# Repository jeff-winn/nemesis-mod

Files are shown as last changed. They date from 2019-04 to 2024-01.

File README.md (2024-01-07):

# Nemesis Mod
It started off as me just wanting to play with an Arduino while repurposing some old .NET Gadgeteer hardware I had laying around the house. It turned into quite a bit more than that over the months that I worked on it. Hopefully the source code will help someone interested in replicating the success I had with my project with their own. Happy coding!

| Branch | Status |
| --- | ---|
| master |   |

## Setting up your environment
Because this project requires the use of symbolic links, you will need to use the command line to clone the repository. Visual Studio Code can do it, but it does not permit symbolic links by default.

```shell
git clone -c core.symlinks=true 
```

## Hardware Requirements
These are the boards and hardware being used by the project:
- [Adafruit Feather M4 Express](https://www.adafruit.com/product/3857) - Mainboard sketch
- [Adafruit Micro SD SPI or SDIO Card Breakout Board](https://www.adafruit.com/product/4682)
- [Tactile Button Switch (6mm square, 5mm tall)](https://www.adafruit.com/product/367)
- [Pololu Dual G2 High-Power Motor Driver 18v18 Shield for Arduino](https://www.pololu.com/product/2515)
- [Pololu G2 High-Power Motor Driver 18v17](https://www.pololu.com/product/2991)
- [Pololu 5V, 500mA Step-Down Voltage Regulator](https://www.pololu.com/product/2843)

### Optional Hardware
- [Adafruit Feather nRF52840 Express](https://www.adafruit.com/product/4062) - Bluetooth sketch
- [MaxAmps LiPo 3250 3S 11.1v Battery Pack](https://www.maxamps.com/lipo-3250-3s-11-1v-battery-pack)

## Bluetooth Support
If you wish to use the Bluetooth connectivity included with this device, please see the Wiki page.

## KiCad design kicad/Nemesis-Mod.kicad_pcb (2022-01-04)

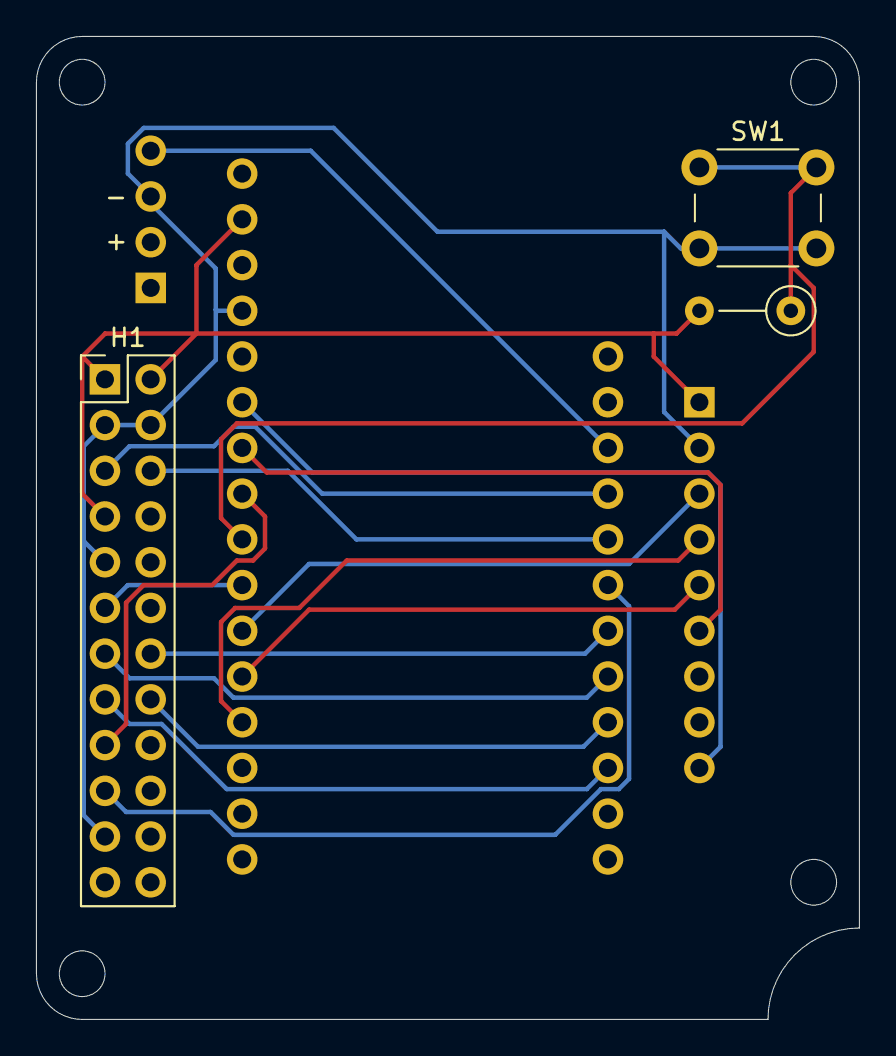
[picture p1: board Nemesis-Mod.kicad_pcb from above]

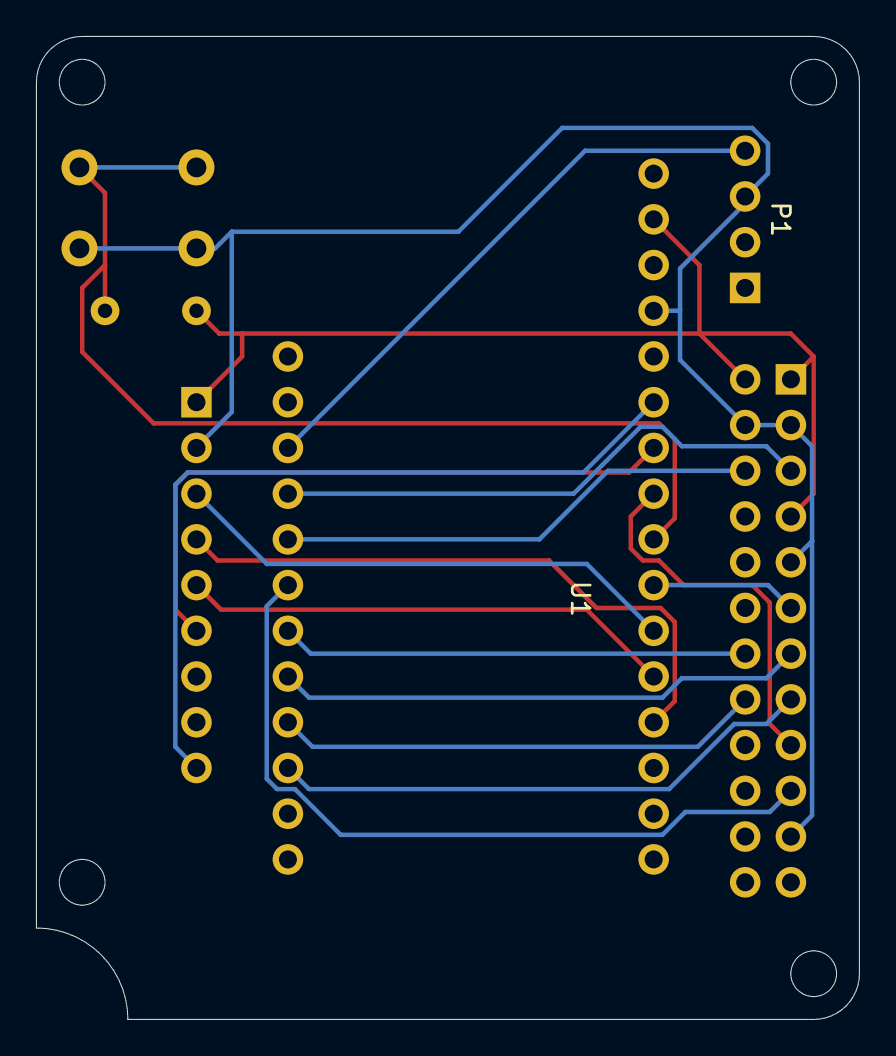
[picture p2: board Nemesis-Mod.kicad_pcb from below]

Board: 2 copper layers, 45.7 x 54.6 mm, 6 parts (2 on the bottom side), 18 nets.

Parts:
H1: PinHeader_2x12_P2.54mm_Vertical
MCU1: Adafruit_Feather_M4_Express
P1: Pololu_5V_Step_Down_Regulator; 5V_Step_Down_Regulator_500mA
R1: 10K; R_Axial_DIN0207_L6.3mm_D2.5mm_P5.08mm_Vertical
SW1: SW1; SW_PUSH_6mm
U1: Adafruit_MicroSD_SPI_Breakout; Adafruit_MicroSD_Breakout

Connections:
+3V3: H1.1, H1.2, H1.7, MCU1.2 (3V), R1.2, U1.1 (3V)
+5V: MCU1.19 (USB), P1.4 (VOUT)
/Mainboard/FIRE_DOWN: H1.6, MCU1.21 (12)
/Mainboard/M1PWM: H1.15, MCU1.26 (5)
/Mainboard/M1SLP: H1.13, MCU1.24 (9)
/Mainboard/M2PWM: H1.16, MCU1.25 (6)
/Mainboard/M2SLP: H1.14, MCU1.23 (10)
/Mainboard/M3PWM: H1.19, MCU1.22 (11)
/Mainboard/M3SLP: H1.17, MCU1.8 (A3)
/Mainboard/RESET_DOWN: MCU1.9 (A4), R1.1, SW1.1
/Mainboard/REV_DOWN: H1.5, MCU1.20 (13)
/Mainboard/SD_DETECT: MCU1.6 (A1), U1.9 (DET)
/Mainboard/SD_SELECT: MCU1.7 (A2), U1.6 (CS)
/Mainboard/SOFT_LOCK1: H1.11, MCU1.10 (A5)
/Mainboard/SPI_CLK: MCU1.11 (SCK), U1.3 (CLK)
/Mainboard/SPI_M_IN: MCU1.13 (MI), U1.4 (SO)
/Mainboard/SPI_M_OUT: MCU1.12 (MO), U1.5 (SI)
GND: H1.3, H1.4, H1.9, H1.21, MCU1.4 (Gnd), P1.3 (GND), SW1.2, U1.2 (GND)

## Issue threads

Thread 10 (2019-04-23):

Add a battery kill switch

jeff-winn, 2019-04-23:
The LiPo pack will need a voltage monitor attached to a kill switch on the firing loop.

This ensures the battery stays within a safe operating voltage to prevent it from being damaged.

jeff-winn, 2019-05-13:
This will need a JST-XH connector and a 5V to 3.3V logic level converter as the LiPo pack has a 4.2V output at full charge from the battery balance connector.

Possible product:
https://www.adafruit.com/product/757

jeff-winn, 2019-11-12:
This would be nice if the BLEBas service can be added within the BluetoothController setup in #42 to display battery levels remotely.

jeff-winn, 2019-11-18:
https://www.adafruit./product/1085

The above ADS1115 product was selected for identifying the battery levels.

jeff-winn, 2019-11-18:
A new battery monitor service needs to be added so the notifications from the battery and the ADS1115 can be transmitted to the BluetoothController and exposed by the BLEBas service.

jeff-winn, 2021-12-02:
Duplicate of #80

Closed 2021-12-02.

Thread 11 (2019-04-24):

Rework for 18v17 motor driver

jeff-winn, 2019-04-24:
The Pololu G2 18v17 motor driver needs to be installed to drive the belt motor.

Closed 2019-04-26.

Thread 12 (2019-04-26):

Optimize the motor speeds

jeff-winn, 2019-04-26:
The flywheel and feed controllers both contain values that determine the motor speeds at the various MotorSpeed enum values.

These values need to be optimized for best case scenarios to ensure proper operation. Specifically the belt drive when on max setting is so fast the rounds just bounce out of the belt and the agitator throws them back up into the hopper.

Closed 2019-05-22.

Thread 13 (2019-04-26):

Add hopper lock switch support

jeff-winn, 2019-04-26:
The hopper lock switch needs to be added to the design. The initial idea would just use an interrupt based software lock to prevent the blaster firing without the hopper installed.

Closed 2019-04-27.

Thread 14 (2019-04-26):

Add support for the 5V stepdown voltage regulator

jeff-winn, 2019-04-26:
The 5V voltage regulator needs to be installed between the 18v18 motor shield and the Feather.

https://www.pololu.com/product/2843

Also consider adding a USB Power Multiplexer to allow the battery pack to remain connected while also allowing a panel mounted USB port allowing external reprogramming of the device. This will still require the 5V voltage regulator if this option were implemented.

https://www.pololu.com/product/2596

Closed 2019-04-27.

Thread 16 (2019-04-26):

Need means of authenticating the operator

jeff-winn, 2019-04-26:
Currently the authentication lock is disabled but in order to enable speeds higher than the default the operator must have a means of authenticating themselves.

Possibilities:
- Bluetooth and a connected app with fingerprint recognition
- Built in biometric fingerprint reader

jeff-winn, 2019-05-26:
This issue will be solved using the Bluetooth and connected application route using an authenticate command.

See #28 for more information.

jeff-winn, 2019-06-24:
This item will need issue #25 completed to ensure the data passed along during authentication is validated against data stored on the device.

Closed 2019-06-30.

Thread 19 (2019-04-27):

Add power multiplexer

jeff-winn, 2019-04-27:
Need to add a USB power multiplexer to handle power switching and external programming support for the blaster while it's pieced together.

Potential product:
https://www.pololu.com/product/2596
https://www.adafruit.com/product/3258

The panel mount could be used to plug into the multiplexer, and use the second pins to receive power from 5V power regulator. This option would also require having a USB Micro B breakout cable connect from the output pins into the Feather USB Micro B.

Closed 2019-06-26.

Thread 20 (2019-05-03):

Stops firing occasionally

jeff-winn, 2019-05-03:
Not entirely sure what the source of the problem is however here are the symptoms:

- Both flywheel motors stop turning (most commonly seen after extended use)
- Single flywheel motor stops turning (usually results in the second flywheel motor seeing a significant speed increase)
- Belt drive motor stops turning

jeff-winn, 2019-05-16:
Doesn't seem to be related to the either Pololu driver, after bypassing the triggers and forcing the rev and firing triggers to be high the drivers operated as expected with continuous current.

jeff-winn, 2019-05-16:
Regarding the previous comment, the motors were not connected to the drivers at this point.

jeff-winn, 2019-05-16:
Rapidly enabling and disabling the rev trigger the M2 output pins on the 18v18 shield worked as expected.

jeff-winn, 2019-05-16:
Able to replicate the issue using a jumper from the power line directly to pin 13. The motor driver was operating as expected with 11VDC on the output going toward the motors. At the motor was the 11 VDC as well, but the motors were not spinning.

jeff-winn, 2019-05-17:
Second attempt to replicate the issue again using the above method proved successful, the boards underneath the motors had the 11 VDC, but were not passing the current into the motors.

jeff-winn, 2019-05-18:
The issue could be related to the way the braking was being done when the triggers were pressed and released rapidly. Modifying the code to give the motors a slowed braking versus massive braking directly to zero seems to have a positive effect on the capacitors near the motors.

Also, rewired the FLT pins to the SLP pins to allow the microcontroller disabling the motor driver and allowing the motors to coast to a stop.

jeff-winn, 2019-05-20:
The code changes to use a slowed braking had no impact on the capability for the motors to run longer than 30 seconds. Removed the stock board underneath the motors with the leads soldered directly to the wires.

Will likely need another change to solder capacitors from the terminals to the motor case to reduce signal noise. Possibly using the capacitors that were on the board.

jeff-winn, 2019-05-20:
After speaking to some folks on Slack, there is a component in the center of the board below that may be a polyfuse (aka resettable fuse) which is disabling the motors due to the increased current.

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

jeff-winn, 2019-05-20:
After further investigation, the component in the center is an HR16-110 PPTC resettable fuse which is likely the culprit why it would stop firing after 30 seconds, and then couldn't fire again for a while after. The electrical characteristics for the part indicates it'd take an hour our two for it to recover.

Considering removal of the component and using a jumper between the two pins.

jeff-winn, 2019-05-20:
The board used for the belt feed had a similar component on it as well near the positive terminal as HR16-065. The approach used to correct the flywheel assembly would need to be replicated on this component board as well.

Closed 2019-05-20.

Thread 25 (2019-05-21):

Unable to retain settings beyond reset

jeff-winn, 2019-05-21:
The hardware does not support EEPROM or FRAM for storage of configuration settings that persist beyond restart of the device.

jeff-winn, 2019-05-23:
Closing as issue #28 will provide better support for configuration and wouldn’t leave the blaster in a potentially harmful configuration if children find it.

jeff-winn, 2019-06-23:
Decided to reopen this so the settings don’t need to be reapplied constantly.

Also the blaster will need some data stored locally to be used to validate what’s being transmitted for authentication.

Closed 2019-06-27.

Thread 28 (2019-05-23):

Need Bluetooth support for configuration

jeff-winn, 2019-05-23:
The Bluefruit LE MCU should be better utilized by handling communication for:

- Diagnostic data
- Trim settings for zero
- Configuration of the belt speed and flywheel speed

jeff-winn, 2019-05-23:
This might be a good way to move settings from the blaster on EEPROM or FRAM into profiles on the connected device that just set all the configurations.

jeff-winn, 2019-06-10:
Merged to master

Closed 2019-06-10.

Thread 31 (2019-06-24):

Need command to set authentication data

jeff-winn, 2019-06-24:
There needs to be a command which will set the authentication data on the device if none is present, or require the operator to authenticate prior to allowing the authentication data to be modified.

jeff-winn, 2019-06-25:
Requires the completion of issue #25 prior to starting this issue.

jeff-winn, 2019-06-29:
Needs the iOS companion application to determine how long the authentication data will be.

jeff-winn, 2019-06-29:
This will be set when the first authentication has been performed, and the reset button on the device being held for 30 seconds or more will allow wiping all the information on the FRAM if needed.

Closed 2019-06-30.

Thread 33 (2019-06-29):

Need to transmit diagnostic data

jeff-winn, 2019-06-29:
The blaster needs to be able to transmit diagnostic data to the iOS companion application for monitoring battery health, current output, etc.

The following data points are required from Motor_Driver_1:
- M1CS
- M2CS

The following data points are required from Motor_Driver_2:
- CS

More information may be added after issue #10 has been closed and something is monitoring the battery health via the balance connector.

jeff-winn, 2019-11-12:
This should now be enabled by #42 and exposing GATT characteristics with no write permission and read only with notification on the client

jeff-winn, 2019-11-18:
The GATT notification characteristics worked as expected. The value from the flywheel M1 and M2 sensors along with the belt M1 sensor has been exposed as characteristics with a read notification with no write privileges.

As the blaster is active it will transmit notifications much more frequently to the connected device.

jeff-winn, 2019-11-18:
Need to connect the blaster up to the battery pack and see what data comes across to the connected device.

Closed 2019-11-28.

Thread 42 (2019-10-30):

Adopt new Feather nRF52 Bluefruit mainboard

jeff-winn, 2019-10-30:
The mainboard needs to be modified to support the nRF52 Bluefruit LE mainboard with ARM M4F chipset.

See:
https://www.adafruit.com/product/3406

jeff-winn, 2019-11-12:
The GATT characteristics and services made it much easier to write the connection mechanism between the companion app and the blaster.

jeff-winn, 2019-11-12:
There should be a waitForEvent method available to the main board which can disable the cpu until GPIO interrupt occurs

jeff-winn, 2019-11-12:
Resolved in #44

Closed 2019-11-12.

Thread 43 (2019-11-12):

Reset button should also clear Bluetooth bonds

jeff-winn, 2019-11-12:
To ensure only a single Bluetooth connection can be established to the blaster, the advertising packets should only be started if the device is not already paired.

Along with this, pressing the reset button should also clear the Bluetooth controller bonds as well as the app data.

Perhaps this also means the reset should be done outside the app control?

jeff-winn, 2019-11-12:
This will be enabled by #42

jeff-winn, 2019-11-13:
The Bluefruit API doesn’t seem to have any methods exposed to indicate whether the device has been paired.

The connected callback must be setup to check whether the handle has been paired and set a setting on the FRAM chip which can be used for the advertisement decision.

Closed 2019-11-27.

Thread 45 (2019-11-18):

Must use pin code while pairing

jeff-winn, 2019-11-18:
The pairing process needs a display to show the pairing value for confirmation by the user on their device.

Without this, the pairing process does not use a secure channel and the blaster never identifies as having been paired (even if pairing has occurred).

To secure the blaster, it must be able to identify whether the connected device has successfully negotiated the pairing process.

jeff-winn, 2019-11-18:
This issue will require the procurement of a display (preferably I2C supported).

jeff-winn, 2019-11-18:
There could be a limitation on the Bluefruit API blocking the implementation of this enhancement.

jeff-winn, 2021-12-08:
Upgraded the firmware on the bluetooth board to version 1.2.0, there appears to be a new security section under Bluefruit that may be usable.

jeff-winn, 2021-12-08:
The board added support for static pin numbers, so that was used rather than setting up a display.

Closed 2021-12-08.

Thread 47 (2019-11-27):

Flywheel speed should change when active

jeff-winn, 2019-11-27:
The flywheel speed currently requires a reset of the trigger to take effect. The expectation is it should be immediate.

Closed 2019-11-28.

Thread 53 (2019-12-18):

Opening the hopper to refill resets the blaster configuration

jeff-winn, 2019-12-18:
Since the hopper lock cuts power to the MCU, whenever the hopper is open the restarting of the MCU causes the settings the shooter is currently using (feed and flywheel speeds) to be reset to their startup configuration.

When used in a battle, this will definitely be an issue with rapidly refilling the rounds in the hopper and resuming play.

jeff-winn, 2019-12-18:
Need to consider removal of the hopper lock, or changing the lock to use an input pin to determine whether the hopper is currently open.

jeff-winn, 2019-12-19:
Rather use a soft lock that can be controlled using a Bluetooth characteristic whether it’s engaged.

This will allow keeping the lock intact when in “kid mode”

Closed 2019-12-21.

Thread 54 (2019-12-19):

Use JST PH connector for power connection

jeff-winn, 2019-12-19:
The current hardware configuration uses the USB pin and GND pins to power the device using the Pololu 5V 500mA step-down voltage regulator.

This regulator should be switched out for a 3.3v 500mA step-down voltage regulator and use a JST PH  2-pin connector to connect to the MCU.

**Example products:**
- [Voltage Regulator](https://www.pololu.com/product/2842)
- [JST PH 2-pin Connector](https://www.adafruit.com/product/261)

jeff-winn, 2019-12-19:
Just wanted to note,

The 3.3V pin on the Pololu high power dual motor controller would be pass through from the Arduino if used as a shield as expected. This pin does not originate from the motor controller and could not be used to power the MCU.

jeff-winn, 2019-12-23:
The primary concern with this connection is the Adafruit board assumes you want to do LiPo charging when a pack and USB are connected.

They’re presuming their small single cell LiPo is directly connected to the board.

jeff-winn, 2019-12-23:
Closing due to concerns about power management. The multiplexer route with USB or the LiPo pack would be better.

Closed 2019-12-23.

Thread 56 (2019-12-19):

Ludicrous speed tearing rounds apart

jeff-winn, 2019-12-19:
With only one set of flywheels getting the rounds up to speed is causing the “yellow dust” effect whereby the rounds are being shredded by the flywheels while firing.

Perhaps using a 2 stage setup to get the rounds up to speed would reduce this effect.

jeff-winn, 2019-12-23:
This might end up being the catalyst to move toward a brushless setup and custom flywheels.

jeff-winn, 2019-12-23:
This problem is not uncommon with rival rounds when using a 3S LiPo battery pack

jeff-winn, 2019-12-23:
Switching to ESCs and brushless motors would require expansion of the PWM signal as the pins on the MCU are limited.

jeff-winn, 2021-12-02:
Removing from R3 as this seems common with a 3S upgrade.

Closed 2021-12-06.

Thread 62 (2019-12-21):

Changing settings occasionally causes the blaster to stop firing (or logging)

jeff-winn, 2019-12-21:
Not sure which this is but if the settings are changed rapidly, the blaster can either stop logging that the blaster is revving and firing, or the blaster is actually rendered inoperable.

jeff-winn, 2019-12-25:
Confirmed this does cause the blaster to cease firing altogether. The rev trigger stops working along with the firing trigger.

jeff-winn, 2019-12-25:
It doesn't stop responding to bluetooth based input, so it could be a bug somewhere in the driver from Adafruit

jeff-winn, 2019-12-25:
This bug could also be due to how the companion app is communicating with the blaster over the GATT services when updating the settings too rapidly.

jeff-winn, 2019-12-25:
When the blaster is frozen it also will not allow attaching to bluetooth GATT notification services. The companion application will freeze when attaching to the device.

jeff-winn, 2019-12-25:
Changing the settings while the blaster was actively in use also caused problems with the device freezing in whichever state it was in (if firing it keeps firing until reset).

jeff-winn, 2019-12-28:
Changing anything via bluetooth while the blaster is revving flywheels will cause the blaster to stop responding along with never leave the loop.

jeff-winn, 2019-12-30:
Changing the setWriteCallback to false when initializing the GATT services does not have any impact on the logic freezing. Perhaps this is a client side issue more than a peripheral side issue?

jeff-winn, 2019-12-30:
The issue is definitely occurring due to the setWriteCallback being used, removing the callbacks negated the issue. However, if the callback is not used, changing the values that are stored on FRAM will be much more difficult as the values would need to be pulled from the GATT characteristics rather than FRAM.

jeff-winn, 2020-09-04:
Had the issue occur again today, I was testing #65 to make sure everything looked good before merging.

jeff-winn, 2021-05-19:
This could be resolved by #71

jeff-winn, 2021-12-04:
Just needs to be triaged whether the bug has been fixed now that the logic has been separated.

jeff-winn, 2021-12-06:
Issue has been resolved by #70 and #71

Closed 2021-12-06.

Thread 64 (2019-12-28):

Add GATT characteristic for battery levels

jeff-winn, 2019-12-28:
The BLEBas service can be used to display battery levels on a device.

Determining the battery voltage at 3.4V per cell at 0% and 4.2V at 100% would be a good indication.

jeff-winn, 2019-12-28:
https://www.adafruit.com/product/4226

Potential product which could be used to measure reference voltage from the battery. Expected use would be in between the flywheel motor shield and the step down converter from Pololu.

jeff-winn, 2021-12-02:
Duplicate of #80

Closed 2021-12-02.

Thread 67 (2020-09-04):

FeedController does not stop when rev trigger is released first

jeff-winn, 2020-09-04:
There's a very small gap whereby the rev trigger can be released before the firing trigger. When this happens, the feed controller continues on until the rev trigger is pulled, released, and pulled a second time.

jeff-winn, 2020-09-04:
There seems to be a secondary issue with the physical design that the trigger won't let the rev trigger extend far enough to cut it off. Effectively allowing the rev trigger to be released and applying enough pressure on the firing trigger causes them both to reactivate.

Closed 2020-09-04.

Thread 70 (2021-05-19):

Connect the Bluetooth board to the mainboard

jeff-winn, 2021-05-19:
With the Bluetooth functionality separated into a secondary board, the data handled there must be passed to the mainboard for processing.

It should:
- Initialize as a slave on the bus while the mainboard is master.
- Receive the data and route the information into a transfer buffer.
- Flag the mainboard it has data waiting through an interrupt pin.
- Have the mainboard pull the data in.
- Have the mainboard process the command received.

jeff-winn, 2021-05-19:
The nRF52840 board does not seem to share pin 13 with the standard on-board LED that Arduinos come with. As such, flagging the interrupt will require the LED_RED to be flagged as well.

jeff-winn, 2021-11-28:
Pin A0 should be used as after removal of the current sensor data, these pins are freed and the devices can be stacked rather than separated via DuPont wires.

jeff-winn, 2021-11-28:
The CircularBuffer library can be used as a ring buffer for holding the data waiting for transfer, and commands received (like clear bonds). So as the request commands are received by the slave, they should also be placed into a receive buffer and processed via the main loop.

This ensures any commands processed do not affect the interrupt negatively. It just grabs the data and moves it.

Closed 2021-12-01.

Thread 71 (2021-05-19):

Separate the Bluetooth processing to a second board

jeff-winn, 2021-05-19:
The nrf52832 may be experiencing issues with the process freezing due to the communication received from the client.

Allowing the Bluetooth processing to occur on a secondary board should alleviate the main processor from having to handle both functions.

This should:
- Introduce an M4 express and move the main logic to this sketch
- Replace the nrf52832 with an nrf52840 express

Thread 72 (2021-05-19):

Change the current sensors to use UART

jeff-winn, 2021-05-19:
The current sensing function is much too rapid to occur over a GATT characteristic and only occurs via notifications of a change.

As such, this should likely occur over UART for more constant updates if turned on.

The on/off switch should likely still be a characteristic so the power isn’t being wasted with nothing listening.

jeff-winn, 2021-12-02:
When enabled, having the log stream flow to the Bluetooth device could be super helpful for people using it that don’t have a debugger.

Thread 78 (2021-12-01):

Create custom board to mount hardware

jeff-winn, 2021-12-01:
To ensure the boards do not get burned out by accidental connections being mismatched, a custom board should be manufactured and mounted within the blaster.

jeff-winn, 2021-12-06:
Reopened the issue since it's still pending fabrication, will need to close the issue once fabrication has been completed and the board has been tested successfully after completion.

jeff-winn, 2021-12-11:
#90 will likely require the board be redesigned slightly as the FRAM storage device is currently attached to this.

jeff-winn, 2021-12-25:
Hardware installed and tested successfully within the blaster after complete reassembly.

Closed 2021-12-25.

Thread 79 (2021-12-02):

Set LED on NRF52 when rxBuffer has data

jeff-winn, 2021-12-02:
As a user, it’s very valuable to me to see when the board is actively processing commands. As such it would be helpful if th LED on the NRF52 was lit when inbound and outbound data is waiting to be processed.

jeff-winn, 2021-12-06:
The LED is currently set on/off by the InterruptPin, which means this will need to be broken apart so the LED and interrupt can function independently of each other.

Closed 2021-12-06.

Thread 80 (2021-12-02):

Add LiPo fuel gauge

jeff-winn, 2021-12-02:
As a user, I need to know when the blaster is close to running out of power.

This will need to support two independent features:
- Kill switch (shuts down the blaster motors)
- GATT characteristic for battery level

Also, this must support 3S along with 2S LiPo (optional).

jeff-winn, 2021-12-06:
Here's an example fuel gauge using the MAX17043G+U IC from Maxim Integrated:
https://www.sparkfun.com/products/10617

Datasheet for the above mentioned IC:
https://datasheets.maximintegrated.com/en/ds/MAX17043-MAX17044.pdf

GitHub project for an example:
https://github.com/sparkfun/SparkFun_MAX17043_Particle_Library

GitHub project for the breakout board:
https://github.com/sparkfun/Lipo_Fuel_Gauge

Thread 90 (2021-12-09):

Use an SD card rather than FRAM

jeff-winn, 2021-12-09:
As a user, I would like the ability to set my own pin for the Bluetooth connection bonding without having to compile the software myself. Because the current mechanism requires the use of the FRAM chip, and the difficulty to set it up is high having an externalized SD card I can plug into my computer to set the value in would be extremely helpful.

jeff-winn, 2021-12-09:
Potential hardware:
https://www.adafruit.com/product/4682

This appears to also require the use of the SD library since it's SPI based, nor does the Feather M4 Express seem to support SDIO.

jeff-winn, 2021-12-11:
The configuration settings class in the master device will likely need to absorb this change in technology.

Still not sure whether JSON or an INI style file should be used.

Closed 2022-01-04.

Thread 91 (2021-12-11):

Missing documentation

jeff-winn, 2021-12-11:
The following documentation needs to be updated from the vendors:
- SAMD21 needs to be SAMD51
- The 5V regulator is missing documentation

Closed 2021-12-12.

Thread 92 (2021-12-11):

Change PIN to use config setting

jeff-winn, 2021-12-11:
The pairing pin for the Bluetooth connection is currently hard coded, this means someone has to know how to recompile and deploy to change the value.

This value should likely come from the master device and passed into the Bluetooth device during init prior to starting advertise.

jeff-winn, 2021-12-11:
This is dependent on #90 as a prerequisite

jeff-winn, 2021-12-13:
#97 relocated the PIN to come from the configuration settings class, so now it's just dependent on the configuration settings being loaded from another bit of hardware.

jeff-winn, 2022-01-04:
Already completed with #90

Closed 2022-01-04.

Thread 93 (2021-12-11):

Produce UF2 file for releases rather than the bin files

jeff-winn, 2021-12-11:
For deployments to devices, having all of the arduino tools installed, ensuring all the dependencies are being installed can be quite cumbersome for someone just wanting to use the product. The feather products come with a bootloader that accepts UF2 files to aid deployment by dragging and dropping the files onto the device using the USB cable without any additional software.

As a user, this would greatly increase adoptability for ease of deployment.

Here's a couple helpful links I found:
- https://github.com/microsoft/uf2/blob/master/utils/uf2conv.md
- https://learn.adafruit.com/adafruit-feather-m4-express-atsamd51/uf2-bootloader-details
- https://github.com/Seeed-Studio/Seeed_Arduino_USBDISP/issues/7

jeff-winn, 2021-12-11:
The following link contains the documentation to generate custom uf2 files for deployment to the nRF52 feather hardware:
https://github.com/adafruit/Adafruit_nRF52_Bootloader

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

jeff-winn, 2021-12-12:
The outputs were successfully deployed to the devices during testing of the changes prior to merging the code.

Closed 2021-12-12.

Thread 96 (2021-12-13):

Change to brushless flywheel motors

jeff-winn, 2021-12-13:
As a consumer faster is always better. The 3S LiPo currently in use is at capacity for how fast the motors can go.

Introducing a single stage brushless setup would continue to improve the FPS at the barrel.

This means:
- A brushless ESC must be introduced
- The motors at the flywheels need to be brushless

The motors may need to be lower RPM and larger to produce more torque to get the inertia overcome.

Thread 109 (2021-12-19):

Unit testing

jeff-winn, 2021-12-19:
As a user, having firmware i can rely upon working consistently over time is extremely important.

The quality gate shows failure because the test coverage is at 0%.

jeff-winn, 2021-12-19:
I really just want one unit test to work for this to pass. The addition of unit testing as a capability within the codebase is important enough that 4.0 will require more modifications to enable better test coverage anyway.

jeff-winn, 2022-01-04:
https://github.com/wjszlachta/arduino-googletest-sample

This sample might be a good resource to lean on to figure out how to apply it.

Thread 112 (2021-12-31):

Use multiplier for motor PWM

jeff-winn, 2021-12-31:
As a user being able to swap out equipment is helpful for reducing cost. The current values used by the PWM signals are specific to the motor driver being used.

Rather than using a hard value in the code, use a multiplier instead with the actual value coming from the config file on the SD card.

jeff-winn, 2021-12-31:
Related to #90

jeff-winn, 2022-01-04:
Most likely the config file will need to store a percentage between 0 and 100 to indicate the motor strength. This value would be used in defining the percentage of the motors for the flywheels and the pusher.

The motor controller min and max defines the actual values specific to the driver/ESC being used that gets multiplied by the percentage to determine the actual value fed into the PWM generator.

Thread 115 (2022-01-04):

Sonar C++ version may be wrong

jeff-winn, 2022-01-04:
The arduino cli may be hiding which c++ version is being applied to sonar during the scanning process, or the ide is applying the wrong standard for the c++ extension.

This should match up so the sonar findings are accurate to the version of c++ being used.

Closed 2022-01-04.

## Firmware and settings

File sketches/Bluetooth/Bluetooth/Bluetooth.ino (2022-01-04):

#include "src/BLEController.h"
#include "src/commands/I2cCommandFactory.h"
#include "src/I2cController.h"

void setup() {
    BLE.setCallback(OnBluetoothCommandReceived);

    I2CBus.init(OnI2cPacketReceived);
    I2CBus.notifyReady();
}

void loop() {
    I2CBus.checkForAsyncCommands();
}

void OnI2cPacketReceived(const uint8_t type, const uint8_t subtype, const uint8_t* data, const uint8_t len) {
    auto command = I2cCommands.create(type, subtype);
    if (command != nullptr) {
        command->execute(data, len);
        delete command;
    }
}

void OnBluetoothCommandReceived(const uint8_t type, const uint8_t subtype, const uint8_t* data, const uint8_t len) {
    I2CBus.sendPacket(type, subtype, data, len);    
}

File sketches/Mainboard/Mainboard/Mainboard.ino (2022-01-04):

#include <Arduino.h>
#include <SPI.h>
#include <Wire.h>

#include "src/App.h"
#include "src/Button.h"
#include "src/Mainboard.h"

const uint16_t CLEAR_HOLD_IN_MSECS = 30000;  // 30 seconds
const uint16_t RESET_HOLD_IN_MSECS = 5000;   // 5 seconds
const uint32_t RESET_BUTTON_PIN = 18;

Button ResetButton(RESET_BUTTON_PIN, true);

void setup() {
    SPI.begin();
    Wire.begin();
    
    ResetButton.init();
    Application.init();
}

void loop() {
    if (ResetButton.isPressed()) {
        handleResetAttempt();
    }
    else {
        Application.run();
    }
}

void handleResetAttempt() {    
    auto started = millis();
    while (ResetButton.isPressed()) {
        MCU.delaySafe(50);
    }

    auto diff = millis() - started;
    if (diff >= CLEAR_HOLD_IN_MSECS) {
        Application.clear();
    }
    else if (diff >= RESET_HOLD_IN_MSECS) {
        Application.reset();
    }
}

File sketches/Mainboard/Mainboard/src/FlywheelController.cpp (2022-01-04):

#include <stddef.h>

#include "ConfigurationSettings.h"
#include "FlywheelController.h"
#include "Mainboard.h"

FlywheelController Flywheels = FlywheelController();

FlywheelController::FlywheelController() {
    m_driver = DualG2HighPowerMotorShield18v18(9, 0, 5, 0, A0, 10, 0, 6, 0, A1);
}

void FlywheelController::init() {
    m_driver.init();
    m_driver.calibrateCurrentOffsets();
    m_driver.disableDrivers();

    auto speed = Settings.getFlywheelSpeed();
    setSpeed(speed);
    
    MCU.delaySafe(1);
}

unsigned int FlywheelController::getMotorCurrentMilliamps(FlywheelMotor motor) {
    switch (motor) {
        case FlywheelMotor::Motor1:
            return m_driver.getM1CurrentMilliamps();
        
        case FlywheelMotor::Motor2:
            return m_driver.getM2CurrentMilliamps();

        default:
            return 0;
    }
}

void FlywheelController::onStart() {
    m_driver.enableDrivers();
    updateDrivers();
}

void FlywheelController::updateDrivers() {
    m_m1Speed = calculateMotorSpeed(FlywheelMotor::Motor1);
    m_m2Speed = calculateMotorSpeed(FlywheelMotor::Motor2);
    m_driver.setSpeeds(m_m1Speed, m_m2Speed);
    
    MCU.delaySafe(1);
}

int FlywheelController::calculateMotorSpeed(FlywheelMotor motor) {
    auto maximumSpeed = determineMotorMaximumSpeed();
    
    auto limiter = calculateLimiterForSpeed(maximumSpeed);
    auto adjustment = getMotorSpeedAdjustment(motor);
    
    return (maximumSpeed - limiter) + (limiter * adjustment);
}

int FlywheelController::calculateLimiterForSpeed(int speed) {
    return speed * Settings.getFlywheelTrimVariance();
}

int FlywheelController::determineMotorMaximumSpeed() {
    switch (m_speed) {
        case FlywheelSpeed::Low:
            return Settings.getFlywheelLowSpeed();
        
        case FlywheelSpeed::Normal:
            return Settings.getFlywheelNormalSpeed();
        
        case FlywheelSpeed::Max:
            return Settings.getFlywheelMaxSpeed();
            
        default:
            return 0; // Disable the motor (speed could not be determined).
    }
}

float FlywheelController::getMotorSpeedAdjustment(FlywheelMotor motor) {
    switch (motor) {
        case FlywheelMotor::Motor1:
            return Settings.getFlywheelM1TrimAdjustment();
        
        case FlywheelMotor::Motor2:
            return Settings.getFlywheelM2TrimAdjustment();

        default:
            return 1;
    }
}

void FlywheelController::onStop() {
    m_driver.setSpeeds(0, 0);
    m_driver.disableDrivers();

    MCU.delaySafe(1);
    m_m1Speed = 0;
    m_m2Speed = 0;
}

FlywheelSpeed FlywheelController::getSpeed() {
    return m_speed;
}

void FlywheelController::setSpeed(FlywheelSpeed speed) {
    m_speed = speed;

    if (isRunning()) {
        updateDrivers();
    }
}

void FlywheelController::setMotorSpeedAdjustment(FlywheelMotor motor, float adjustment) {
    if (adjustment < 0) {
        return;
    }

    switch (motor) {
        case FlywheelMotor::Motor1: {
            Settings.setFlywheelM1TrimAdjustment(adjustment);
            break;
        }
        case FlywheelMotor::Motor2: {
            Settings.setFlywheelM2TrimAdjustment(adjustment);
            break;
        }
    }

    if (isRunning()) {
        updateDrivers();
    }
}

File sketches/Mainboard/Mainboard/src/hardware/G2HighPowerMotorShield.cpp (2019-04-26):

#include "G2HighPowerMotorShield.h"

boolean G2HighPowerMotorShield::_flip = false;

// Constructors ////////////////////////////////////////////////////////////////
G2HighPowerMotorShield::G2HighPowerMotorShield() {  
}

G2HighPowerMotorShield::G2HighPowerMotorShield(unsigned char SLEEP,
                                               unsigned char DIR,
                                               unsigned char PWM,
                                               unsigned char FAULT,
                                               unsigned char CS)
{
  _SLEEP = SLEEP;
  _FAULT = FAULT;
  _DIR = DIR;
  _PWM = PWM;
  _CS = CS;
}

// Public Methods //////////////////////////////////////////////////////////////
void G2HighPowerMotorShield::init()
{
  pinMode(_SLEEP, OUTPUT);
  pinMode(_PWM, OUTPUT);
  pinMode(_FAULT, INPUT_PULLUP);
  pinMode(_CS, INPUT);
  pinMode(_DIR, OUTPUT);

#ifdef G2HIGHPOWERMOTORSHIELD_TIMER1_AVAILABLE
  if (_M1PWM == _M1PWM_TIMER1_PIN && _M2PWM == _M2PWM_TIMER1_PIN)
  {
    // Timer 1 configuration
    // prescaler: clockI/O / 1
    // outputs enabled
    // phase-correct PWM
    // top of 400
    //
    // PWM frequency calculation
    // 16MHz / 1 (prescaler) / 2 (phase-correct) / 400 (top) = 20kHz
    TCCR1A = 0b10100000;
    TCCR1B = 0b00010001;
    ICR1 = 400;
  }
#endif
}
// Set speed for motor 1, speed is a number betwenn -400 and 400
void G2HighPowerMotorShield::setSpeed(int speed)
{
  unsigned char reverse = 0;

  if (speed < 0)
  {
    speed = -speed;  // Make speed a positive quantity
    reverse = 1;  // Preserve the direction
  }
  if (speed > 400)  // Max PWM dutycycle
    speed = 400;

#ifdef G2HIGHPOWERMOTORSHIELD_TIMER1_AVAILABLE
  if (_M1PWM == _M1PWM_TIMER1_PIN && _M2PWM == _M2PWM_TIMER1_PIN)
  {
    OCR1A = speed;
  }
  else
  {
    analogWrite(_M1PWM, speed * 51 / 80); // map 400 to 255
  }
#else
  analogWrite(_PWM, speed * 51 / 80); // map 400 to 255
#endif

  if (reverse ^ _flip) // flip if speed was negative or _flipM1 setting is active, but not both
  {
    digitalWrite(_DIR, HIGH);
  }
  else
  {
    digitalWrite(_DIR, LOW);
  }
}

// Return error status for motor 1
unsigned char G2HighPowerMotorShield::getFault()
{
  return !digitalRead(_FAULT);
}

void G2HighPowerMotorShield::flip(boolean flip)
{
  G2HighPowerMotorShield::_flip = flip;
}

// Enables the MOSFET driver for M1.
void G2HighPowerMotorShield::enableDriver()
{
  digitalWrite(_SLEEP, HIGH);
}

// Puts the MOSFET driver for M1 into sleep mode.
void G2HighPowerMotorShield::disableDriver()
{
  digitalWrite(_SLEEP, LOW);
}

unsigned int G2HighPowerMotorShield::getCurrentReading()
{
  return analogRead(_CS);
}

// Set voltage offset of M1 current reading at 0 speed.
void G2HighPowerMotorShield::calibrateCurrentOffset()
{
  setSpeed(0);
  enableDriver();
  delay(1);
  G2HighPowerMotorShield::_offset = getCurrentReading();
}

// Return M1 current value in milliamps using the gain value for the specific version.
unsigned int G2HighPowerMotorShield::getCurrentMilliamps(int gain)
{
  // 5V / 1024 ADC counts / gain mV per A
  // The 24v14, 18v18 and 24v18 results in 244 mA per count.
  // The 18v22 results in 488 mA per count.
  unsigned int mAPerCount = 5000000/1024/gain;
  int reading = (getCurrentReading() - G2HighPowerMotorShield::_offset);
  if (reading > 0)
  {
    return reading * mAPerCount;
  }
  return 0;
}
// Return M1 current value in milliamps for 18v22 version.
unsigned int G2HighPowerMotorShield18v17::getCurrentMilliamps()
{
  return G2HighPowerMotorShield::getCurrentMilliamps(10);
}

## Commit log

2019-01-20 Updating documentation.
    Adding hardware and toolset details to the documentation in case anyone wants to reproduce it.
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2019-01-23 Adding the FlywheelController to manage the flywheel motors.
2019-01-23 Correcting the name of button1.
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2019-01-24 Fixing motor direction.
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2019-01-24 Fixing build issues (integrated with Arduino IDE)
2019-01-25 Corrected issues with the potentiometer support.
    [FlywheelController.cpp, Motor.cpp]
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2019-01-29 Fixing a couple extra includes.
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2019-02-01 Removing the namespaces (issue with execution on the hardware).
    [FlywheelController.cpp, Motor.cpp]
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2019-02-09 Redesigning the flywheel controller for the new motor shield.
    [FlywheelController.cpp, Motor.cpp]
2019-02-09 Completing replacement of the L298 to Pololu motor controller.
    [FlywheelController.cpp]
2019-02-10 Removing the PWM library dependencies as it is no longer needed.
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2019-02-10 Changing the level of power savings to ensure correct PWMing functions.
    [FlywheelController.cpp]
2019-02-11 Fixing an issue with the flywheel assembly during start and stop.
    [FlywheelController.cpp]
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2019-02-21 Replacement of mainboard to Feather M0.
    [FlywheelController.cpp, Mainboard.cpp]
2019-02-21 Correcting the motor pin.
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2019-03-09 Correcting the name of the sleep function.
    [Mainboard.cpp]
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2019-05-20 Updated factory design with missing board.
2019-05-20 Correcting design after removal of boards.
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2019-05-23 Updating schematics and documentation.
    [Nemesis-Mod.kicad_pcb, Nemesis-Mod.sch]
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2019-06-10 Correcting folder name casing.
    [FlywheelTrimAdjustmentCommand.cpp, G2HighPowerMotorShield.cpp]
2019-06-22 Adding Adafruit I2C FRAM breakout packages.
    [Nemesis-Mod.sch]
2019-06-22 Stubbing out the configuration settings class.
    [ConfigurationSettings.h]
2019-06-22 Stubbing out the ConfigurationSettings class.
    [ConfigurationSettings.h]
2019-06-23 Adding destructor.
    [ConfigurationSettings.h]
2019-06-23 Moving the configuration constants to the settings class.
    [ConfigurationSettings.h]
2019-06-23 Adding settings reset support.
    [ConfigurationSettings.h]
2019-06-23 Adding set accessors to the configuration settings.
    [ConfigurationCommand.h, ConfigurationSettings.h]
2019-06-25 Adding configuration settings addresses.
    [ConfigurationSettings.h]
2019-06-26 Stubbing the ChangeConfigurationSettingCommand class.
    [ConfigurationCommand.h]
2019-06-26 Adding command to change configuration settings.
    [ConfigurationSettings.h]
2019-06-27 Adding float support for configuration settings.
    [ConfigurationSettings.h]
2019-06-27 Adding support for trim adjustment settings and on-the-fly reconfiguration.
    [ConfigurationSettings.h]
2019-06-27 Stubbing methods for authentication token.
    [ConfigurationSettings.h]
2019-06-28 Initial adding software reset button support.
    [Nemesis-Mod.sch]
2019-06-29 Adding deauthentication support.
    [ConfigurationSettings.h]
2019-06-29 Updating schematic.
    [Nemesis-Mod.sch]
2019-06-29 Updating the schematic.
    [Nemesis-Mod.sch]
2019-06-29 Adding support for authentication tokens.
    [ConfigurationSettings.h]
2019-06-30 Correcting reset button connections.
    [Nemesis-Mod.sch]
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2019-10-31 Updating schematics for new hardware.
    [Nemesis-Mod.sch]
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2019-11-01 Updating schematics.
    [Nemesis-Mod.sch]
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2019-11-04 Refactoring for simplification.
    [ConfigurationSettings.h]
2019-11-04 Breaking out the AuthenticationToken_t type.
    [ConfigurationSettings.h]
2019-11-04 Refactoring changes.
    [ConfigurationCommand.h]
2019-11-07 Correcting UUIDs (Confirmed using working Arduino example)
2019-11-09 Removing authentication mechanism until it can be implemented with BLE.
    [ConfigurationSettings.h]
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2019-11-09 Restructuring services.
    [ConfigurationService.h]
2019-11-09 Restructuring code.
    [ConfigurationService.h]
2019-11-10 Adding support for changing configuration settings.
    [ConfigurationService.h]
2019-11-11 Adding support for flywheel trim variance configuration.
    [ConfigurationService.h]
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2019-11-12 Correcting board version.
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2019-11-18 Adding support for storing whether a paired connection exists.
    [ConfigurationSettings.h]
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2019-11-28 Adding hopper lock to schematic.
    [Nemesis-Mod.sch]
2019-11-28 Adding support for belt max speed characteristic.
    [ConfigurationService.h]
2019-12-01 Changing how the controllers are initialized.
    [ConfigurationSettings.h]
2019-12-06 Fixing include guards.
    [ConfigurationCommand.h, ConfigurationSettings.h]
2019-12-06 Fixing convention for private member instances.
    [ConfigurationService.h]
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2019-12-07 Renaming flywheel speeds.
    [ConfigurationSettings.h]
2019-12-16 Adding support for flywheel speed characteristics.
    [ConfigurationService.h]
2019-12-17 Fixing bug with logging precision.
    [FlywheelController.cpp]
2019-12-17 Adding support for additional belt speed characteristics.
    [ConfigurationService.h]
2019-12-17 Fixing bug with the trim adjustments not being persisted.
    [FlywheelController.cpp]
2019-12-18 Changing the controllers to use the settings to prevent requiring reset to change configuraiton.
    [FlywheelController.cpp]
2019-12-19 Rewiring for soft hopper lock.
    [Nemesis-Mod.sch]
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2019-12-20 Correcting schematic for VIN and GND to MCU.
    [Nemesis-Mod.sch]
2019-12-21 Adding hopper lock characteristic support.
    [ConfigurationService.h, ConfigurationSettings.h]
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2020-09-13 Cleaning up schematic.
    [Nemesis-Mod.kicad_pcb, Nemesis-Mod.sch]
2020-09-13 Fixing kicad file ignore.
2020-09-14 Relocating files.
    [ConfigurationCommand.h, ConfigurationService.h, ConfigurationSettings.h]
2020-09-14 Updating schematic date.
    [Nemesis-Mod.sch]
2021-11-24 Removing Bluetooth support to transfer to the M4 express mainboard.
    [ConfigurationService.h]
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2021-11-24 Correcting pins to match new mainboard.
    [FlywheelController.cpp]
2021-11-24 Correcting MCU1 to Feather M4.
    [Nemesis-Mod.sch]
2021-11-25 Cleanup - fixing compilation warnings.
    [FlywheelController.cpp]
2021-11-25 Rearranging workspace.
    [ConfigurationCommand.h, ConfigurationService.h, ConfigurationSettings.h]
2021-11-25 Reorganizing sketches.
    [ConfigurationCommand.h, ConfigurationService.h, ConfigurationSettings.h]
2021-11-25 Correcting sketch locations.
    [ConfigurationCommand.h, ConfigurationService.h, ConfigurationSettings.h]
2021-11-25 Reconfiguring sketches.
    [ConfigurationCommand.h, ConfigurationService.h, ConfigurationSettings.h]
2021-11-25 Relocating source files.
    [ConfigurationService.h]
2021-11-25 Enabling bluetooth services and controller.
    [ConfigurationService.h]
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2021-11-27 Relocating the configuration settings to shared folder.
    [ConfigurationSettings.h]
2021-11-27 Moving files back to the master i2c device.
    [ConfigurationSettings.h]
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2021-11-29 Correcting startup support to being advertising.
    [Bluetooth.ino, I2cController.cpp]
2021-11-29 Reintroducing commands.
    [ConfigurationCommand.h]
2021-11-29 Changing command to reset NRF52 device.
    [I2cController.cpp]
2021-11-29 Fixing delete for arrays.
    [I2cController.cpp]
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2021-12-01 Adding support for remaining characteristics.
    [ConfigurationService.h]
2021-12-04 Adding custom board for consolidating pins.
    [Nemesis-Mod.kicad_pcb, Nemesis-Mod.sch]
2021-12-06 Fixing schematic issues after double checking before fabrication.
    [Nemesis-Mod.kicad_pcb, Nemesis-Mod.sch]
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2021-12-06 Upgrading KiCad project to v6.
    [Nemesis-Mod.kicad_pcb, Nemesis-Mod.kicad_sch, Nemesis-Mod.sch]
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2021-12-08 Reworking the schematic layout.
    [Nemesis-Mod.kicad_sch, feed.kicad_sch, flywheels.kicad_sch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]
2021-12-08 Updating PCB to match schematic.
    [Nemesis-Mod.kicad_pcb, Nemesis-Mod.kicad_sch, main.kicad_sch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]
2021-12-08 Updating layout.
    [main.kicad_sch]
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2021-12-13 Relocating the PIN value to the settings. (#100)
    [ConfigurationSettings.h]
2021-12-13 Fixing some issues with the PCB layout after manfacturing completed. (#101)
    * Correcting pad sizes for custom footprints.
    * Correcting courtyard size for M4 express.
    * Correcting courtyard width for M4 express.
    [Nemesis-Mod.kicad_pcb]
2021-12-14 Adding on-board documentation for power. (#103)
    [Nemesis-Mod.kicad_pcb]
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2021-12-18 Cleaning up some SonarQube bugs. (#107)
    * Fixing bug.
    * Fixing a couple sonar bugs.
    [I2cController.cpp]
2022-01-04 Feature/sd card (#113)
    * Updating design to use SD card.
    * Changing the config settings to use an ini file.
    * Adding example blaster ini file.
    * Update blaster.ini
    * Update blaster.ini
    * Update blaster.ini
    * Update blaster.ini
    * Update blaster.ini
    * Update blaster.ini
    * Restructuring the examples.
    * Cleanup.
    * Update basic.ini
    * Relocating SPI init.
    * Moving filename to header.
    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
    [ConfigurationCommand.h, ConfigurationService.h, ConfigurationSettings.h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]
2022-01-04 Attempting to fix Sonar scanning C++ version.
    Resolves #115
